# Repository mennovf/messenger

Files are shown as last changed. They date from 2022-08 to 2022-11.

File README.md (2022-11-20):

# Hearted Messenger
This repository contains instructions and code to build a small hardware device which shows a random sequence of messages, being both text and pictures.
The messages are stored and read in a simple binary format for space savings. This repository constructs these binaries from a Facebook Messenger chat, filtered on the ❤ reaction and seperated by author.
There's a power button to connect the + line of the battery to the arduino's 5V pin. A potentiometer controls the duration before switching to the next (random) message in the sequence. Its range is 1s-60s, and is infinite if the pot is >95%. Finally, there's a push button to toggle between the two message authors.

## Demonstration

Demo A demonstration of the final working project.

## Usage
### Dependencies
- Arduino
- ImageMagick
- python3
- bash
- lv_font_convert (installed globally with npm)

### Font
The font required some work to get working. For better resemblance to the Messenger look and visual appearance, a variable-width font was required. This requires a lot of work to use the additional pregenerated information for the kerning.
Luckily I found the lv_font_convert tool of the [lvgl](https://github.com/lvgl/lvgl) project. This tool creates C structures with for a predetermined size of the font. The code to work with these structures has been extracted from lvgl itself. Only the necessary font files were copied and modified for this use.

#### PROGMEM
The fonts take up a lot of space. Too much for the limited RAM of the arduino. The Arduino Mega does have enough memory, but it is part of the program memory page of its harvard architecture processor.
The default lvgl font code assumes all of the font data is accessible in RAM, but this would not work for this setup. I have modified the font code to use the pgm* family of functions to allocate some parts of the font to this progmem area and access them accordingly.
For the fonts generated with lv_font_convert to work with this modified code, PROGMEM attributes should be added to required arrays. To see which parts need this attribute, you should look at the Roboto.c font in this repository as reference.

#### Characters

During message baking, a python script creates a list of all the unique characters present in the messages. By feeding these into lv_font_convert a lot of memory is saved.

See the [message baking](#baking) section for an explanation on the baking step. 

Roboto was the font which most resembled Messenger's. I used Font Forge to combine Robot with [Noto](https://fonts.google.com/noto/specimen/Noto+Emoji) for the emojis, which are plentiful in chat conversations.

### Messages
#### Binary Format
The binary format is pretty easy, as it doesn't need to do a lot. It has been created to have fast random access (literally). Integers are big-endian.

The contents of the file are:

| Element | Type |
|---|---|
| N (# messages) | u32 |
| Message Offsets | u32[N] |
| Message Data | Message[] |
The values in the message offsets array determine where a new message starts from the beginning of the message data array. This offsets array is necessary for the random access.

Message is another structure:

| Field | Type |
|---|---|
| Message Type | u8 |
| Message Data | u8[] or u8[12] |

Message Type can be either 0 for text messages, and 1 for an image. The message data for text messages is a null-terminated utf-8 string, whereas for images it is the name of the image filename as baked.

#### Baking
The baking is done with several tools and a python script. The input is the archive of your Messanger chat from facebook.

Downloading the Messenger archive is the zeroeth baking step. In desktop browser:
1. Click on _your profile_, _ Settings and Privacy_ and then _Settings_.
2. In the list on the left, click on _Your Facebook Information_
3. Choose _Download a copy of your information_
4. The _Format_ has to be JSON. _Media Quality_ can probably be low since the display is only 480x320.
5. Deselect everything but _Messages_ so the file size can be vastly decreased and the processing duration on Facebook's end to prepare the archive is way shorter.
6. _Request Download_ at the bottom of the page.
7. Wait untill Facebook notifies you through either facebook itself or email. At this point you have about four days to download the archive.

The first step converts all images, gifs and videos into still frame .bmps. For videos the first frame is used, for gifs the last. This is because most gifs have some setup and their last frame best summarizes their content. Videos are harder to summarize but the first frame seems best. Bmp is a somewhat easy format to parse, although I had some issues initially with the different header versions, compressions and the pixel line alignment to 4 bytes.
The code assumes a certain format for the bmp, but not all of the assumed parameters can be explicitly controlled in ImageMagick. This means the image rendering might break for some images or even break in general in the future.
The generated bmp files are collected in the images/ folder.

The second baking step is the python script to combine and convert the JSON files in the Messenger chat. Messenger creates multiple JSON files for a chat to limit their size. These files contain a lot more information which we won't need for this project.
The script loops through every message, skips it if it doesn't have a ❤ reaction and collects it by author. The filenames in messages that are an image, gif or video message are mapped to an [8.3 filename](https://en.wikipedia.org/wiki/8.3_filename#:~:text=8.3%20filenames%20are%20limited%20to,filenames%2C%20excess%20characters%20are%20ignored.) and their corresponding .bmp file is renamed and copied to a directory of actually used images. In the end, each author's messages are written in the binary format above, and all the unicode codepoints are written to a temporary file.

The final step creates the C structures from the Roboto font for the rendering. The font.sh file contains the instructions to lv_font_convert to create these files with the codepoints from the previous step.

### Circuit

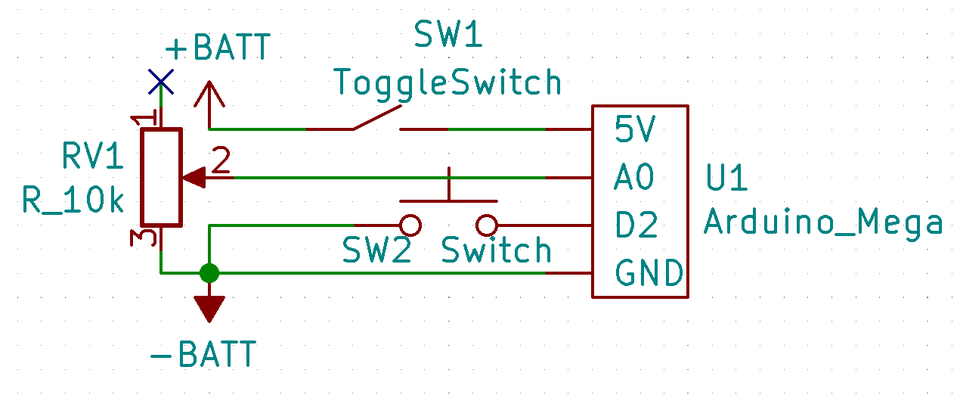
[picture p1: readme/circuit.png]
circuit Circuit


Both the potentiometer and the button work by enabling the internal pull-up resistor of their connected pin. For the potentiometer, this creates a voltage divider where the potential on the input pin at  the max setting of 10k is about 1.1V, the internal reference voltage set in code. For lower resistor values the potential drops, using the full adc range at the input.
The internal pull-up for the button is necessary to distinguish between pressed (0V at the input) and unpressed (1 at the input).
In both cases, the internal pull-up greatly simplifies the design and wiring.

### Case

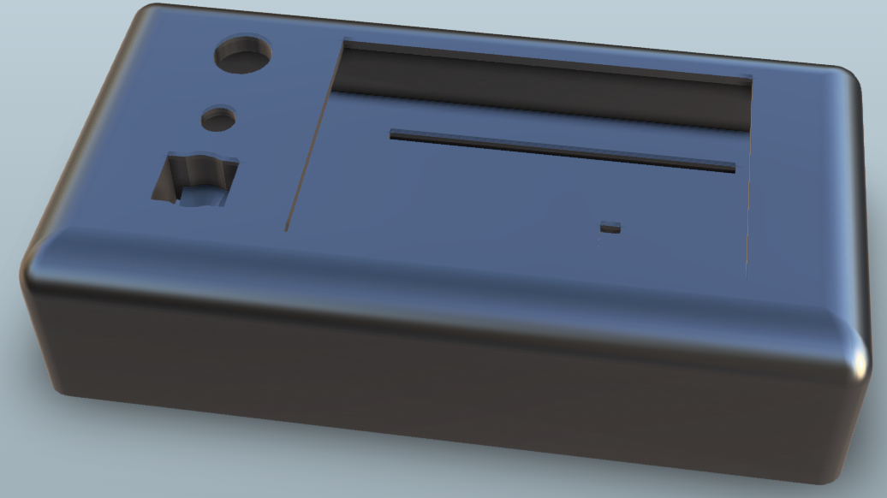
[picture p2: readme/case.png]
Case Full Case


Case Explosion Explosion view of the case model

The case is designed in Fusion 360 and modelled in three parts. 
- The bottom part holds a battery and is drawn for a specific powerbank model. It has a cutout to monitor the battery level. The small basin next to it provides space for the USB A and leftover wiring.
- The base part is to seperate the battery from the arduino and has cutouts to hold the arduino mega in place with its pins.
- The top part has a holes for the screen, the power button, the transition speed potentiometer and the _author toggle_ push button.

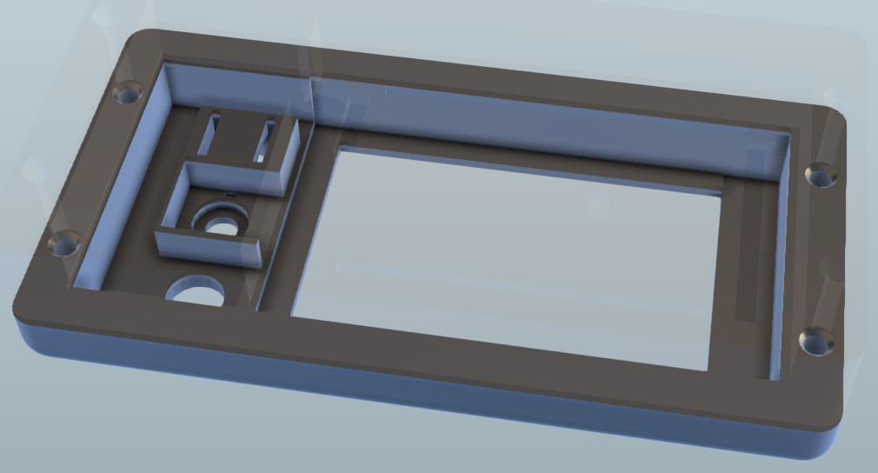
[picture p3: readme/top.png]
Top Part Details of the top part


The whole is held together by M3x40mm screws. They need M3 thread inserts melted into the Top part's holes.

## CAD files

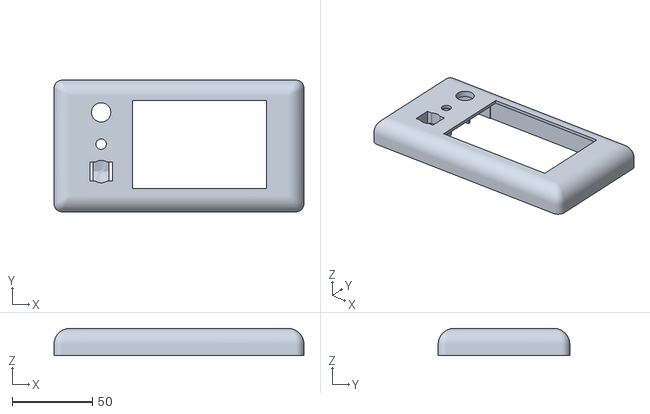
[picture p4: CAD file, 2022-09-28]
case/export/Top.stl
155.7 x 82.0 x 17.0

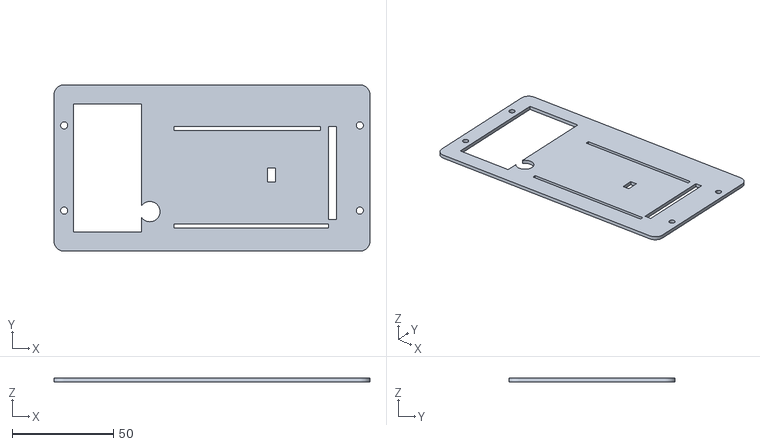
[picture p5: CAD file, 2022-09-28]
case/export/Middle.stl
155.7 x 82.0 x 2.00

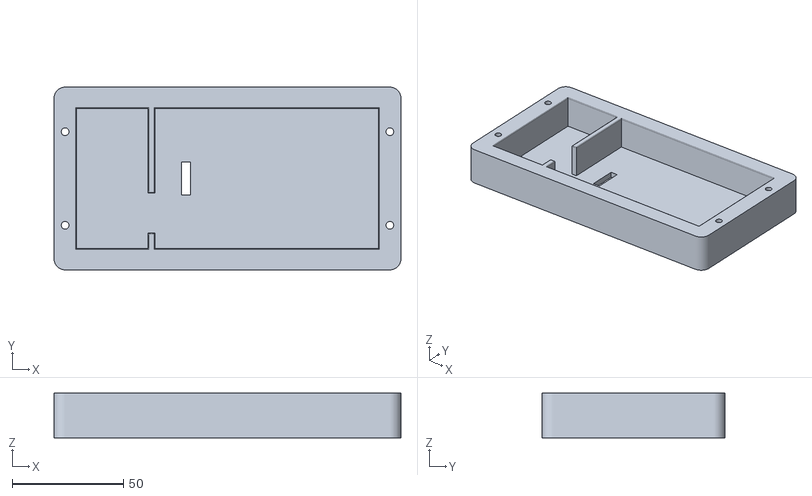
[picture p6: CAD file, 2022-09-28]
case/export/Base.stl
155.7 x 82.0 x 20.0

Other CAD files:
case/Case.f3d

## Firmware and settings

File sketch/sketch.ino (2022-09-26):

// IMPORTANT: LCDWIKI_KBV LIBRARY MUST BE SPECIFICALLY
// CONFIGURED FOR EITHER THE TFT SHIELD OR THE BREAKOUT BOARD.

//This program is a demo of how to show a bmp picture from SD card.

//Set the pins to the correct ones for your development shield or breakout board.
//the 16bit mode only use in Mega.you must modify the mode in the file of lcd_mode.h
//when using the BREAKOUT BOARD only and using these 16 data lines to the LCD,
//pin usage as follow:
//             CS  CD  WR  RD  RST  D0  D1  D2  D3  D4  D5  D6  D7  D8  D9  D10  D11  D12  D13  D14  D15 
//Arduino Mega 40  38  39  /   41   37  36  35  34  33  32  31  30  22  23  24   25   26   27   28   29

//Remember to set the pins to suit your display module!

/**********************************************************************************
* @attention
*
* THE PRESENT FIRMWARE WHICH IS FOR GUIDANCE ONLY AIMS AT PROVIDING CUSTOMERS
* WITH CODING INFORMATION REGARDING THEIR PRODUCTS IN ORDER FOR THEM TO SAVE
* TIME. AS A RESULT, QD electronic SHALL NOT BE HELD LIABLE FOR ANY
* DIRECT, INDIRECT OR CONSEQUENTIAL DAMAGES WITH RESPECT TO ANY CLAIMS ARISING
* FROM THE CONTENT OF SUCH FIRMWARE AND/OR THE USE MADE BY CUSTOMERS OF THE 
* CODING INFORMATION CONTAINED HEREIN IN CONNECTION WITH THEIR PRODUCTS.
**********************************************************************************/

#include <SD.h>
#include <SPI.h>
#include <stdint.h>
#include <limits.h>
#include <string.h>
#include <avr/sleep.h>
#include <avr/interrupt.h>
#include "src/LCDWIKI_GUI.h" //Core graphics library
#include "src/LCDWIKI_KBV.h" //Hardware-specific library
#include "src/lvgl/lvgl.h"

//the definiens of 16bit mode as follow:
//if the IC model is known or the modules is unreadable,you can use this constructed function
LCDWIKI_KBV my_lcd(ILI9486,40,38,39,1,41); //model,cs,cd,wr,rd,reset

#define BLACK   0x0000
#define BLUE    0x001F
#define RED     0xF800
#define GREEN   0x07E0
#define CYAN    0x07FF
#define MAGENTA 0xF81F
#define YELLOW  0xFFE0
#define WHITE   0xFFFF

#define LENGTH(arr) (sizeof(arr) / sizeof(arr[0]))
#define MAX(a, b) (((a) > (b)) ? (a) : (b))
#define MIN(a, b) (((a) < (b)) ? (a) : (b))

// GLOBALS
uint32_t index_shown = 0;
#define COLOUR_BG (WHITE)
#define COLOUR_TEXT (WHITE)
#define COLOUR_DIALOG (my_lcd.Color_To_565(0x00, 0x7f, 0xf9))
#define COLOUR_NAME (BLACK)
uint16_t s_width;  
uint16_t s_height;
LV_FONT_DECLARE(roboto16)


enum class Person {
  HIM,
  HER
};


static uint32_t const NAME_HIM[] = {0x43c, 0x430, 0x43d, 0x435, 0x447, 0x43a, 0x430, '\0'};
static uint32_t const NAME_HER[] = {0x440, 0x438, 0x442, 0x43e, 0x447, 0x43a, 0x430, '\0'};
static uint32_t const * const NAMES[] = {NAME_HIM, NAME_HER};

volatile Person person = Person::HIM;
volatile uint64_t person_button_changed;
int person_button_previous_value = HIGH;


uint8_t r565(uint16_t c) {
  return (c >> 11) * 8;
}
uint8_t g565(uint16_t c) {
  return ((c >> 5) & 0x3F) * 4;
}
uint8_t b565(uint16_t c) {
  return (c & 0x1F) * 8;
}

uint16_t blend(uint16_t l, uint16_t r, float a) {
  if (a <= 0) return r;
  if (a >= 1) return l;
  float const g = 2.2;
  float Rl = r565(l), Rr = r565(r);
  float Gl = g565(l), Gr = g565(r);
  float Bl = b565(l), Br = b565(r);
  Rl = pow(Rl / 255.f, g);
  Rr = pow(Rr / 255.f, g);
  Gr = pow(Gr / 255.f, g);
  Gl = pow(Gl / 255.f, g);
  Br = pow(Br / 255.f, g);
  Bl = pow(Bl / 255.f, g);

  float rr = Rl * a + Rr * (1.f - a);
  float gg = Gl * a + Gr * (1.f - a);
  float b = Bl * a + Br * (1.f - a);

  uint32_t const R = pow(rr, 1.f / g) * 255;
  uint32_t const G = pow(gg, 1.f / g) * 255;
  uint32_t const B = pow(b, 1.f / g) * 255;

  return my_lcd.Color_To_565(R, G, B);
}

void person_button_interrupt() {
  uint64_t const now = millis();
  person_button_changed = now;
}

Person get_person() {
  int const button_state = digitalRead(2);

  uint64_t const now = millis();
  if (now - person_button_changed > 100) {
    if (person_button_previous_value == HIGH && button_state == LOW) {
      person = static_cast<Person>(!static_cast<bool>(person));
    }

    person_button_previous_value = button_state;
  }

  return person;
}

uint16_t read16le(File fp) {
    uint16_t const low = fp.read();
    uint16_t const high = fp.read();
    return (high<<8)|low;
}
uint32_t read32le(File fp) {
    uint32_t const low = read16le(fp);
    uint32_t const high = read16le(fp);
    return (high << 16) | low;   
}

uint16_t read16(File fp) {
    uint16_t const high = fp.read();
    uint16_t const low = fp.read();
    return (high<<8)|low;
}

uint32_t read32(File fp) {
    uint32_t const high = read16(fp);
    uint32_t const low = read16(fp);
    return (high << 16) | low;   
}

struct BmpHeader {
  uint32_t width;
  int32_t height;
  uint32_t offset;
  uint8_t bpp;
  bool valid;
};
 
struct BmpHeader analyse_bmp_header(File fp) {
    struct BmpHeader header;
    memset(&header, 0, sizeof(header));
    
    if(read16le(fp) != 0x4D42) {
      Serial.println("Magic bytes don't match.");
      return header;  
    }
    //get bpm size
    read32le(fp);
    //get creator information
    read32le(fp);
    //get offset information
    header.offset = read32le(fp);
    //get DIB infomation
    uint32_t const dib_size = read32le(fp);
    if (dib_size != 124) {
      Serial.print(fp.name()); Serial.println(" does not use BITMAPV5HEADER DIB header.");
      return header;
    }
    //get width and heigh information
    header.width  = read32le(fp);
    uint32_t const uheight = read32le(fp);
    memcpy(&header.height, &uheight, sizeof(uheight));
    
    read16le(fp);
    header.bpp = read16le(fp);
    if (!( header.bpp == 24 || header.bpp == 32 )) {
      Serial.print(fp.name()); Serial.println(" does not have RGB encoding.");
      return header;
    }
    // Compression type should be None
    uint32_t const compression = read32le(fp);
    if((header.bpp == 16 && compression != 0) || (header.bpp == 32 && compression != 3)) {
      Serial.print(fp.name()); Serial.print(" uses compression="); Serial.println(compression);
      return header; 
    }
    header.valid = true;
    return header;
}

#define BMP_PIXEL_BUF_AMOUNT (480)

static uint8_t  data[BMP_PIXEL_BUF_AMOUNT*4] = {0};
static uint32_t colors[BMP_PIXEL_BUF_AMOUNT];

void draw_pixel(uint16_t x, uint16_t y, uint16_t c) {
  my_lcd.Draw_Pixe(x, y, c);
}

void draw_nopixel(uint16_t, uint16_t, uint16_t) {
}

void draw_rgb_line(uint16_t x, uint16_t y, uint16_t w, uint32_t const * const colors) {
  my_lcd.Set_Addr_Window(x, y, x+w, y);
  my_lcd.cs_active();
  my_lcd.Write_Cmd8(my_lcd.CC);
  for (int i = 0; i < w; ++i) {
    uint32_t const c = colors[i];
    my_lcd.Write_Data(my_lcd.Color_To_565( (c >> 8) & 0xFF, (c >> 16) & 0xFF, (c >> 24) & 0xFF ));
  }
  my_lcd.cs_idle();
}

typedef void (*DrawBMPLine)(uint16_t, uint16_t, uint16_t, uint32_t const *);

void draw_bmp_picture(BmpHeader header, File fp, int16_t left = -1, int16_t top = -1, DrawBMPLine draw_line = &draw_rgb_line) {
  left = (left >= 0) ? left : (s_width/2 - header.width / 2);
  top  = (top >= 0) ? (top + header.height) : (s_height + header.height - 1) / 2;

  uint32_t pixels_left = header.width * header.height;
  uint8_t const Bpp = header.bpp / 8;

  int const pixels_per_line = MIN(BMP_PIXEL_BUF_AMOUNT, header.width);
  int const bytes_per_line = Bpp*pixels_per_line;
  int const bytes_per_scanline = (bytes_per_line + 3) & ~0x3;

  int16_t line_counter = 0;
  fp.seek(header.offset);
  while (pixels_left > 0) {
    size_t m = 0;
    fp.read(data, bytes_per_scanline);
    for (size_t k = 0; k < pixels_per_line; k++) {
      if (Bpp == 3) colors[k] = ((uint32_t)data[m] << 24) | ((uint32_t)data[m+1] << 16) | ((uint32_t)data[m+2] << 8);
      if (Bpp == 4) colors[k] = ((uint32_t)data[m] << 24) | ((uint32_t)data[m+1] << 16) | ((uint32_t)data[m+2] << 8) | ((uint32_t)data[m+3]);
      m += Bpp;
    }
    draw_line(left, top, pixels_per_line, colors);
    pixels_left -= pixels_per_line;
    top -= 1;
  }  
}



void draw_rounded_rect(LCDWIKI_KBV * const lcd, uint16_t left, uint16_t top, uint16_t width, uint16_t height, uint16_t R, uint16_t color) {
  lcd->Fill_Rect(left + R, top, width - 2*R, height, color);
  lcd->Fill_Rect(left, top + R, R, height - 2*R, color);
  lcd->Fill_Rect(left + width - R, top + R, R + 1, height - 2*R, color);

  // Top left
  for (uint16_t x = left; x < left + R; ++x) {
    for (uint16_t y = top; y < top + R; ++y) {
      float fx = x;
      float fy = y;
      float dx = fx - (left + R);
      float dy = fy - (top + R);
      float D2 = dx*dx + dy*dy;
      if (D2 < R*R) {
        lcd->Draw_Pixe(x, y, color);
      } else {
        float d = sqrt(D2) - R;
        float a = MAX(0, 1.f - d);
        lcd->Draw_Pixe(x, y, blend(color, COLOUR_BG, a));
      }
    }
  }

  // Top Right
  for (uint16_t x = left + width - R; x < left + width + 1; ++x) {
    for (uint16_t y = top; y < top + R; ++y) {
      float fx = x;
      float fy = y;
      float dx = fx - (left + width - R);
      float dy = fy - (top + R);
      float D2 = dx*dx + dy*dy;
      if (D2 < R*R) {
        lcd->Draw_Pixe(x, y, color);
      } else {
        float d = sqrt(D2) - R;
        float a = MAX(0, 1.f - d);
        lcd->Draw_Pixe(x, y, blend(color, COLOUR_BG, a));
      }
    }
  }

  // Bottom left
  for (uint16_t x = left; x < left + R; ++x) {
    for (uint16_t y = top + height - R; y < top + height; ++y) {
      float fx = x;
      float fy = y;
      float dx = fx - (left + R);
      float dy = fy - (top + height - R);
      float D2 = dx*dx + dy*dy;
      if (D2 < R*R) {
        lcd->Draw_Pixe(x, y, color);
      } else {
        float d = sqrt(D2) - R;
        float a = MAX(0, 1.f - d);
        lcd->Draw_Pixe(x, y, blend(color, COLOUR_BG, a));
      }
    }
  }

  // Bottom Right
  for (uint16_t x = left + width - R; x < left + width + 1; ++x) {
    for (uint16_t y = top + height - R; y < top + height; ++y) {
      float fx = x;
      float fy = y;
      float dx = fx - (left + width - R);
      float dy = fy - (top + height - R);
      float D2 = dx*dx + dy*dy;
      if (D2 < R*R) {
        lcd->Draw_Pixe(x, y, color);
      } else {
        float d = sqrt(D2) - R;
        float a = MAX(0, 1.f - d);
        lcd->Draw_Pixe(x, y, blend(color, COLOUR_BG, a));
      }
    }
  }
}

bool is_word_break(uint32_t c) {
  return (c == ' ') || (c == '\n') || (c == '\t') || (c == '\0');
}

struct Line {
  uint16_t start;
  uint16_t end;
};

struct WrappedDesc {
  uint16_t nlines;
  uint16_t line_width;
  Line lines[20];
};

struct WrappedDesc text_wrapping(uint32_t const * text, uint16_t max_width) {
  struct WrappedDesc res;
  memset(&res, 0, sizeof(res));
  
  uint16_t line_width = 0;
  uint16_t word_width = 0;
  uint16_t word_begin = 0;

  bool last = false;
  
  for (int ccount = 0; !last; ++ccount) {
    uint32_t const * const str = text + ccount;
    uint32_t c = *str;
    last = c == '\0';
    uint32_t n = last ? *(str + 1) : '\0';


    // Special case, handle first
    if (line_width == 0 && word_width == 0 && is_word_break(c)) {
        word_begin = ccount + 1;
        res.lines[res.nlines].start = ccount + 1;
        continue;
    }

    uint16_t const char_width = lv_draw_letter(draw_nopixel, 0, 0, &roboto16, c, n, 0, 0);
    word_width += char_width;
    
    if (is_word_break(c)) {
      // Don't take whitespace width into account for wrapping purposes
      if (line_width + word_width - char_width < max_width) {
        res.lines[res.nlines].end = ccount;
        word_begin = ccount + 1;
        line_width += word_width;
        res.line_width = MAX(res.line_width, line_width);
        word_width = 0;
        continue;
      }
      
      // Go try the next line if there's already content on this one
      if (line_width > 0) {
        res.nlines += 1;
        res.line_width = MAX(res.line_width, line_width);
        line_width = 0;
        res.lines[res.nlines].start = word_begin;
  
        // Try to fit it again. If not, start breaking it in pieces
        if (line_width + word_width - char_width < max_width) {
          res.lines[res.nlines].end = ccount;
          word_begin = ccount + 1;
          line_width += word_width;
          res.line_width = MAX(res.line_width, line_width);
          word_width = 0;
          continue;
        }
      }

      // It is too large to fit on the current line: break it up
      int cindex = word_begin;
      while (cindex < ccount) {
        // Determine how many characters can be put into it
        uint16_t part_width = 0;
        uint16_t last_cwidth = 0;
        while (part_width < max_width && cindex < ccount) {
          last_cwidth = lv_draw_letter(draw_nopixel, 0, 0, &roboto16, text[cindex], text[cindex + 1], 0, 0);
          part_width += last_cwidth;
          cindex += 1;
        }

        // Inc'ed once too many
        if (cindex != ccount) {
          cindex -= 1;
        }

        res.lines[res.nlines].end = cindex;
        word_width -= (part_width - last_cwidth);
        word_begin = cindex;

        // Go fill the next line (if this one was filled)
        if (part_width >= max_width) {
          res.nlines += 1;
          res.line_width = MAX(res.line_width, part_width);
          res.lines[res.nlines].start = word_begin;
          line_width = 0;
        }
      }

      word_begin = ccount + 1;
      continue;
    }
  }



  // Convert from index to amount
  res.nlines += 1;
  
  return res;
}

uint16_t draw_string(uint16_t left, uint16_t top, uint32_t const * str, uint16_t col, uint16_t bg) {
  while (*str != '\0') {
    uint32_t c = *str++;
    uint32_t n = *str;
    left += lv_draw_letter(draw_pixel, left, top, &roboto16, c, n, col, bg);
  }
  return left;
}

size_t read_string_into_n(File * const f, uint32_t * buf, size_t n) {
  size_t written = 0;
  
  while (written < n) {
    uint32_t c = 0;
    uint32_t const fb = f->read();
    if ((fb & 10000000) == 0) {
      c = fb;
    }
    if ((fb & 0b11100000) == 0b11000000) {
      uint32_t sb = f->read();
      
      c = ((fb & 0b00011111) << 6) | ((sb & 0b00111111));
    }
    if ((fb & 0b011110000) == 0b11100000) {
      uint32_t sb = f->read();
      uint32_t tb = f->read();
     
      c = ((fb & 0b00011111) << 12) | ((sb & 0b00111111) << 6) | ((tb & 0b00111111));
    }
    if ((fb & 0b11110000) == 0b11110000) {
      uint32_t b2 = f->read();
      uint32_t b3 = f->read();
      uint32_t b4 = f->read();
      c = ((fb & 0b00000111) << 18) | ((b2 & 0b00111111) << 12) | ((b3 & 0b00111111) << 6) | ((b4 & 0b00111111));
    }
    buf[written] = c;
    ++written;

    if (c == '\0') {
      break;
    }
  }
  buf[n - 1] = '\0';
  return written;
}

uint64_t fast_hash(uint64_t h) {
    h ^= h >> 23;
    h *= 0x2127599bf4325c37ULL;
    h ^= h >> 47;
    return h;
}

uint32_t true_random() {
  uint64_t h = 0xFFFFFFFFFF;
  for (int i = 0; i < 64; ++i) {
    uint16_t const v = analogRead(A9);
    h = fast_hash(h ^ v);
    delay(1);
  }
  return h;
}

enum MessageType {
  STRING = 0,
  IMAGE = 1
};


static uint16_t heartxstart;
static uint16_t heartystart;
void draw_heart_line(uint16_t x, uint16_t y, uint16_t w, uint32_t const * const RGBAs) {
  int16_t const d = (int16_t)y - (int16_t)heartystart;
  uint16_t const bg = (d < 8) ? COLOUR_DIALOG : COLOUR_BG;

  my_lcd.Set_Addr_Window(x, y, x+w, y);
  my_lcd.cs_active();
  my_lcd.Write_Cmd8(my_lcd.CC);
  
  for (int i = 0; i < w; ++i) {
    uint32_t const RGBA = RGBAs[i];
    uint8_t Ro = (RGBA >> 8) & 0xFF;
    uint8_t Go = (RGBA >> 16) & 0xFF;
    uint8_t Bo = (RGBA >> 24) & 0xFF;
    float const a = (RGBA & 0xFF) / 255.f;
    uint8_t R = Ro * a + r565(bg) * (1.f - a);
    uint8_t G = Go * a + g565(bg) * (1.f - a);
    uint8_t B = Bo * a + b565(bg) * (1.f - a);
  
    uint16_t const color = my_lcd.Color_To_565(R, G, B);
    my_lcd.Write_Data(color);
  }
  my_lcd.cs_idle();
}

void next_message() {
    char const * const mfile = (person == Person::HIM) ? "/him" : "/her";
    File f = SD.open(mfile, FILE_READ);
    if (!f) {
      Serial.println("Unable to open messages file.");
      return;
    }
    uint32_t const n_messages = read32(f);
    uint32_t const msg_start = 4 + 4*n_messages; // (Last offset points to bmp data area)
   
    uint32_t candidate;
    while ((candidate = random(0, n_messages)) == index_shown);
    Serial.print("Index shown: "); Serial.println(candidate);
    index_shown = candidate;
    //index_shown = 10;
    
    uint32_t const offset_addr = 4 + index_shown*4;
    f.seek(offset_addr);
    uint32_t const msg_offset = read32(f);

    f.seek(msg_start + msg_offset);
    uint8_t const msg_type = f.read();

    if (msg_type == MessageType::STRING) {
      uint32_t buf[130];
      read_string_into_n(&f, buf, LENGTH(buf));     
      f.close(); 

      
      uint16_t const R = 20;
      uint16_t const W = 150;
      // Preparations for drawing
      WrappedDesc wrapping = text_wrapping(buf, W);

      uint16_t const cx = 480 / 2, cy = 320 / 2;
      const uint16_t SPACING = 2;
      uint16_t text_height = roboto16.line_height * wrapping.nlines + SPACING*(wrapping.nlines - 1);
  
      uint16_t bw = wrapping.line_width + 2*R, bh = text_height + 2*R;
  
      // Clear   
      my_lcd.Fill_Screen(COLOUR_BG);

      // Calculate box dimensions
      uint16_t bleft = cx - bw/2;
      uint16_t btop  = cy - bh / 2;
      
      // Draw Writer name
      int16_t wtop = btop - roboto16.line_height;
      if (wtop >= 0) {
        draw_string(bleft + 10, wtop, NAMES[static_cast<int>(person)], COLOUR_NAME, COLOUR_BG);
      }
  
      // Draw box
      draw_rounded_rect(&my_lcd, bleft, btop, bw, bh, R, COLOUR_DIALOG);
  
      // Draw the text
      uint16_t top = cy - text_height/2;
      uint16_t left = cx - wrapping.line_width / 2;
      for (int i = 0; i < wrapping.nlines; ++i) {
        uint32_t const prev = buf[wrapping.lines[i].end];
        buf[wrapping.lines[i].end] = '\0';
        draw_string(left, top, &buf[wrapping.lines[i].start], COLOUR_TEXT, COLOUR_DIALOG);
        buf[wrapping.lines[i].end] = prev;
        top += roboto16.line_height + SPACING;
      }

      // Draw the heart
      File heart = SD.open("/images/heart.bmp");
      if (!heart) {
        Serial.println("Could not read heart.bmp file.");
        heart.close();
        return;
      }

      BmpHeader const heartheader  = analyse_bmp_header(heart);
      heartxstart = bleft + bw - R - heartheader.width;
      heartystart = btop + bh - 8;
      draw_bmp_picture(heartheader, heart, heartxstart, heartystart, draw_heart_line);
      heart.close();
    } else {  
      my_lcd.Fill_Screen(COLOUR_BG);

      //8.3 filenames
      char fname[21] = "/images/";
      f.read(&fname[8], 12);
      fname[8+12] = '\0';
      f.close();

      File imgf = SD.open(fname, FILE_READ);
      if (!imgf) {
        Serial.print("Could not read file ("); Serial.print(index_shown); Serial.print("): "); Serial.println(fname);
        imgf.close();
        return;
      }

      BmpHeader const header = analyse_bmp_header(imgf);
      if (!header.valid) {
        Serial.print("Not a valid bmp ("); Serial.print(index_shown); Serial.print("): "); Serial.println(fname);
        imgf.close();
        return;
      }
      Serial.print("Valid bmp header in  "); Serial.println(fname);

      draw_bmp_picture(header, imgf);
      
    }

}

void setup() {
    pinMode(A9, INPUT);
    uint32_t const SEED = true_random();
    randomSeed(SEED);
    
    // POT
    pinMode(A0, INPUT_PULLUP);
    analogReference(INTERNAL1V1);

    // Person Button
    pinMode(2, INPUT_PULLUP);
    person_button_changed = millis();
    attachInterrupt(digitalPinToInterrupt(2), &person_button_interrupt, CHANGE);
    
    Serial.begin(9600);
    
    my_lcd.Init_LCD();
    my_lcd.Set_Rotation(3);
    s_width = my_lcd.Get_Display_Width();
    s_height = my_lcd.Get_Display_Height();

    //Init SD_Card 
    pinMode(53, OUTPUT);
    if (!SD.begin(53)) {
      Serial.println("Unable to begin SD!");
      my_lcd.Fill_Screen(RED);
      while (true);
    }

    next_message();
}

float pot() {
  uint16_t const a = analogRead(A0);
  return a / 1024.f;
}

void loop() {
    static uint64_t last_change_at = millis();

    float const p = pot();
    uint64_t change_period_ms = (59*p + 1) * 1000;
    if (p > 0.95) {
      change_period_ms = UINT64_MAX;
    }


    static Person last_person = person;
    Person person = get_person();
    
    uint64_t const now = millis();
    if (now - last_change_at > change_period_ms || last_person != person) {
      next_message();
      
      last_change_at = now;
    }

    last_person = person;
}

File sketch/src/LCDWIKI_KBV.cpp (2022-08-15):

// IMPORTANT: LIBRARY MUST BE SPECIFICALLY CONFIGURED FOR EITHER TFT SHIELD
// OR BREAKOUT BOARD USAGE.

// Lcdwiki GUI library
// MIT license

#if defined(__SAM3X8E__)
	#include <include/pio.h>
    #define PROGMEM
    #define pgm_read_byte(addr) (*(const unsigned char *)(addr))
    #define pgm_read_word(addr) (*(const unsigned short *)(addr))
#endif

#include "pins_arduino.h"
#include "wiring_private.h"
#include "LCDWIKI_KBV.h"
#include "lcd_registers.h"
#include "lcd_mode.h"
#if (CONFIG_USE_8BIT_BUS==1)
#include "mcu_8bit_magic.h"
#elif (CONFIG_USE_8BIT_BUS==0)
#include "mcu_16bit_magic.h"
#endif

#define TFTLCD_DELAY16  0xFFFF
#define TFTLCD_DELAY8   0x7F
#define MAX_REG_NUM     24

//static uint8_t have_reset;

//#define LEFT_SHIFT(x) (1<<x) //x value 0:mipi dcs rev1
                             //        1:auto readinc
                             //        2:read bgr
                             //        3:read low and high
                             //        4:read 24 bits
                             //        5:xsa and xea 16 bit
                             //        6:read no dummy
                             //        8:invert gs
                             //        9:invert ss
                             //       10:mv axis
                             //       11:invert rgb
                             //       12:rev screen
                             //       13:filp vert	
			                 //       14:flip horiz

//The mode,width and heigth of supported LCD modules
lcd_info current_lcd_info[] = 
						 { 
							 0x9325,240,320,			
							 0x9328,240,320,
							 0x9341,240,320,
							 0x9090,320,480,
							 0x7575,240,320,
							 0x9595,240,320,
							 0x9486,320,480,
							 0x7735,128,160,
							 0x9488,320,480,
							 0x9481,320,480,
						 };

// Constructor for breakout board (configurable LCD control lines).
// Can still use this w/shield, but parameters are ignored.
// if modules is unreadable or you don't know the width and height of modules,you can use this constructor.
LCDWIKI_KBV::LCDWIKI_KBV(uint16_t model,uint8_t cs, uint8_t cd, uint8_t wr, uint8_t rd, uint8_t reset)
{	
  #ifndef USE_ADAFRUIT_SHIELD_PIN
	  // Convert pin numbers to registers and bitmasks
	  _reset	 = reset;
  #ifdef __AVR__
		csPort	   = portOutputRegister(digitalPinToPort(cs));
		cdPort	   = portOutputRegister(digitalPinToPort(cd));
		wrPort	   = portOutputRegister(digitalPinToPort(wr));
		rdPort	   = portOutputRegister(digitalPinToPort(rd));
  #endif
  #if defined(__SAM3X8E__)
		csPort	   = digitalPinToPort(cs);
		cdPort	   = digitalPinToPort(cd);
		wrPort	   = digitalPinToPort(wr);
		rdPort	   = digitalPinToPort(rd);
  #endif
	  csPinSet	 = digitalPinToBitMask(cs);
	  cdPinSet	 = digitalPinToBitMask(cd);
	  wrPinSet	 = digitalPinToBitMask(wr);
	  rdPinSet	 = digitalPinToBitMask(rd);
	  csPinUnset = ~csPinSet;
	  cdPinUnset = ~cdPinSet;
	  wrPinUnset = ~wrPinSet;
	  rdPinUnset = ~rdPinSet;
  #ifdef __AVR__
		*csPort   |=  csPinSet; // Set all control bits to HIGH (idle)
		*cdPort   |=  cdPinSet; // Signals are ACTIVE LOW
		*wrPort   |=  wrPinSet;
		*rdPort   |=  rdPinSet;
  #endif
  #if defined(__SAM3X8E__)
		csPort->PIO_SODR  |=  csPinSet; // Set all control bits to HIGH (idle)
		cdPort->PIO_SODR  |=  cdPinSet; // Signals are ACTIVE LOW
		wrPort->PIO_SODR  |=  wrPinSet;
		rdPort->PIO_SODR  |=  rdPinSet;
  #endif
	  pinMode(cs, OUTPUT);	  // Enable outputs
	  pinMode(cd, OUTPUT);
	  pinMode(wr, OUTPUT);
	  pinMode(rd, OUTPUT);
	  if(reset) 
	  {
		 digitalWrite(reset, HIGH);
		 pinMode(reset, OUTPUT);
	  }
  #endif
  #ifdef USE_ADAFRUIT_SHIELD_PIN 
  	 CS_IDLE; // Set all control bits to idle state
 	 WR_IDLE;
  	 RD_IDLE;
  	 CD_DATA;
 	 digitalWrite(5, HIGH); // Reset line
 	 pinMode(A3, OUTPUT);   // Enable outputs
 	 pinMode(A2, OUTPUT);
 	 pinMode(A1, OUTPUT);
 	 pinMode(A0, OUTPUT);
  	 pinMode( 5, OUTPUT);
 #endif
 	rotation = 0;
 	lcd_model = current_lcd_info[model].lcd_id;
	WIDTH = current_lcd_info[model].lcd_wid;
	HEIGHT = current_lcd_info[model].lcd_heg;
/*
	switch(lcd_model)
	{
		case 0x7735:
			WIDTH = 128;
			HEIGHT = 160;
		    break;
		case 0x9325:
		case 0x9328:
		case 0x9341:
		case 0x7575:
		case 0x9595:
			WIDTH = 240;
			HEIGHT = 320;
		    break;
		case 0x9486:
			WIDTH = 320;
			HEIGHT = 480;
            break;
		default:
			WIDTH = 0;
			HEIGHT = 0;
			break;
	}
*/
    setWriteDir();
 	width = WIDTH;
	height = HEIGHT;		
}

// Constructor for breakout board (configurable LCD control lines).
// Can still use this w/shield, but parameters are ignored.
// if modules is readable or you know the width and height of modules,you can use this constructor.
LCDWIKI_KBV::LCDWIKI_KBV(int16_t wid,int16_t heg,uint8_t cs, uint8_t cd, uint8_t wr, uint8_t rd, uint8_t reset)
{	
  #ifndef USE_ADAFRUIT_SHIELD_PIN
	  // Convert pin numbers to registers and bitmasks
	  _reset	 = reset;
  #ifdef __AVR__
		csPort	   = portOutputRegister(digitalPinToPort(cs));
		cdPort	   = portOutputRegister(digitalPinToPort(cd));
		wrPort	   = portOutputRegister(digitalPinToPort(wr));
		rdPort	   = portOutputRegister(digitalPinToPort(rd));
  #endif
  #if defined(__SAM3X8E__)
		csPort	   = digitalPinToPort(cs);
		cdPort	   = digitalPinToPort(cd);
		wrPort	   = digitalPinToPort(wr);
		rdPort	   = digitalPinToPort(rd);
  #endif
	  csPinSet	 = digitalPinToBitMask(cs);
	  cdPinSet	 = digitalPinToBitMask(cd);
	  wrPinSet	 = digitalPinToBitMask(wr);
	  rdPinSet	 = digitalPinToBitMask(rd);
	  csPinUnset = ~csPinSet;
	  cdPinUnset = ~cdPinSet;
	  wrPinUnset = ~wrPinSet;
	  rdPinUnset = ~rdPinSet;
  #ifdef __AVR__
		*csPort   |=  csPinSet; // Set all control bits to HIGH (idle)
		*cdPort   |=  cdPinSet; // Signals are ACTIVE LOW
		*wrPort   |=  wrPinSet;
		*rdPort   |=  rdPinSet;
  #endif
  #if defined(__SAM3X8E__)
		csPort->PIO_SODR  |=  csPinSet; // Set all control bits to HIGH (idle)
		cdPort->PIO_SODR  |=  cdPinSet; // Signals are ACTIVE LOW
		wrPort->PIO_SODR  |=  wrPinSet;
		rdPort->PIO_SODR  |=  rdPinSet;
  #endif
	  pinMode(cs, OUTPUT);	  // Enable outputs
	  pinMode(cd, OUTPUT);
	  pinMode(wr, OUTPUT);
	  pinMode(rd, OUTPUT);
	  if(reset) 
	  {
		 digitalWrite(reset, HIGH);
		 pinMode(reset, OUTPUT);
	  }
  #endif
  #ifdef USE_ADAFRUIT_SHIELD_PIN 
  	 CS_IDLE; // Set all control bits to idle state
 	 WR_IDLE;
  	 RD_IDLE;
  	 CD_DATA;
 	 digitalWrite(5, HIGH); // Reset line
 	 pinMode(A3, OUTPUT);   // Enable outputs
 	 pinMode(A2, OUTPUT);
 	 pinMode(A1, OUTPUT);
 	 pinMode(A0, OUTPUT);
  	 pinMode( 5, OUTPUT);
 #endif
 	rotation = 0;
 	lcd_model = 0xFFFF;
    setWriteDir();
	WIDTH = wid;
	HEIGHT = heg;
 	width = WIDTH;
	height = HEIGHT;		
}

// Initialization lcd modules
void LCDWIKI_KBV::Init_LCD(void)
{
	reset();
	if(lcd_model == 0xFFFF)
	{
		lcd_model = Read_ID(); 
	}
//	uint16_t ID = Read_ID(); 
	start(lcd_model);
//	Set_Rotation(0);
}
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

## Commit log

2022-07-25 Better RNG and fix shown_index
    [sketch.ino]
2022-07-26 Fix lvgl unicode_list_compare function
    [sketch.ino]
2022-07-26 Add missing emoji's and fix 4-byte utf-8 parsing
    [sketch.ino]
2022-07-26 Fix rotation and start changing the message periodically
    [sketch.ino]
2022-07-28 Switch on message type
2022-07-30 Fix wrapping box width when actually wrapping
    [sketch.ino]
2022-08-13 Add button logic
2022-08-13 do next_message on person switch
2022-08-15 Fix him/her message filtering and add the name of the writer
    [sketch.ino]
2022-08-15 Fix bmp odd width drawing issue
    [sketch.ino]
2022-09-26 Add small diagram for the external connections
    [messenger.sch]
2022-09-28 Add case files
    [Base.stl, Case.f3d, Middle.stl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]
2022-11-20 Fix circuit image reference
